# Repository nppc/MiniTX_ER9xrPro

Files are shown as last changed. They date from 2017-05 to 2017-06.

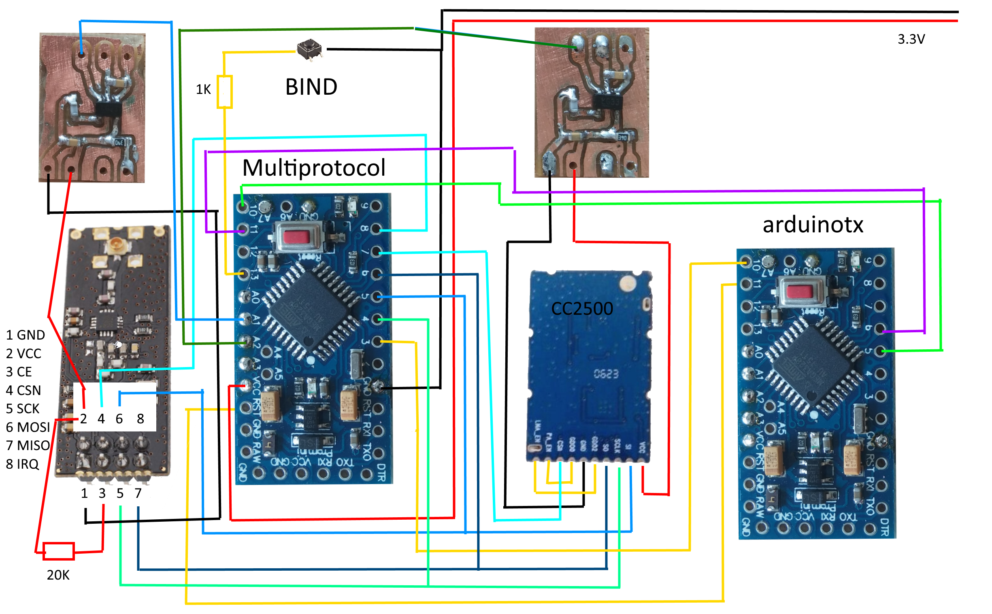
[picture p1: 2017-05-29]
Images/ProjectProtocol.png

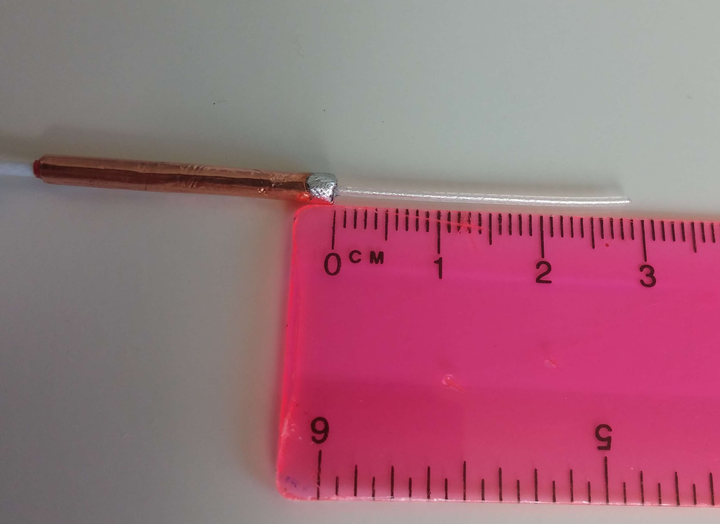
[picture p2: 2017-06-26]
Images/2_4ghzDipole1.jpg

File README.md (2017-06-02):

# MiniTX_ER9xrPro
Project for mini transmitter with gimbals from Er9xr Pro TX
# Transmitter software
Software is based on arduinorc project (http://www.reseau.org/arduinorc) with mine modifications.
Some of the modifications listed here:
- Added PRT variable to Models to store TX Protocol number
- Only configured models are selected with Model button
- Enter/exit Command mode done with push-button, not switch
- After model is selected, correct Protocol is choosed (rotary dip-switch emulation)
- Arming (Throttle Cut) is extended to 2 switches
- some other minor changes

## Change Models
To chnage models or to configure the transmitter, press and hold button "C" for 2 seconds to enter/exit Configuration mode.
So, to change Model you need to go to Configuration mode, press "M" button, and then exit from Configuration mode.
Every press of "M" button changes to the next Model. If next model is not configured, then first model is selected.

## Arm/disarm
Switches on side of the transmitter are used for safe arming. They are both connected to single analog channel A6 with resistors network.
If both swithces are OFF, then Throttle cut mode is activated.
If one of the swithces is ON, then Throttle cut mode is off.
For simple copters one of the switches can be used as arming switch.
For normal FC safe arming with 2 swithes is possible.

## Some Commands for configuring the transmitter
*To configure the transmitter, we need to go to Configure mode. In this mode enabled Serial interface at 2400 baud rate.*
- **DUMP** : print the values of all variables of current model
- **DUMP GLOBAL** : print the values of the Global variables
- **DUMP MODEL** : print the values of the Model variables of the current model
- **DUMP [channel]** : print the values of the Channel variables of the current model
- **DUMP MIXERS** : print the values of the Mixers variables of the current model
- **MODEL [number]** : select the model.
- **? (question mark)** : print the value of a variable (eg ? ICN1)
- **? POTx** : print the analog value of potentiometer x (POT1 = pin A0 ... POT8 = pin A7)
- **? PPM** : print the pulses widths of the PPM signal
- **? SWx** : print the logical value of switch x (SW1 = pin D2 ... SW3 = pin D4)
- **? VERSION** : print the version number of the software
- **? VOLT** : print the battery voltage
- **= (equal sign)** : change the value of a variable (eg ICN1=2)

## Variables for configuring transmitter
- **CDS** : current model ; this is the model number selected by the MODEL command.
- **TSC** : throttle cutoff value used by the throttle security check, [0-511] default = 50.
- **BAT** : minimum voltage required for Tx operation, an alarm is triggered when voltage gets lower. Value in the range [0-1023] default = 740.
- **KL1...KL8** : lowest analog value read on potentiometer #1, when the stick (and the hardware trim, if any) is at its lowest position. KL1...KL8 correspond to potentiometers 1 to 8. Value in the range [0-1023] default = 0.
- **KH1...KH8** : highest analog value read on potentiometer #1, when the stick (and the hardware trim, if any) is at its highest position. KH1...KH8 correspond to potentiometers 1 to 8. Value in the range [0-1023] default = 1023.

## Variables for configuring Models general data
- **NAM** : Model name, 8 characters, no spaces
- **THC** : Channel number used for throttle control, default=3, 0=no throttle channel.
- **PRT** : Protocol number of the Multiprotocol module that should be selected for current model. 1-FRSKYX_8CH, 2-FRSKYX_16CH, 3-FRSKYD, 4-FRSKYV, 5-BAYANG(H8), 6-BAYANG(H8S3D), 7-SYMAX (see Multiprotocol _Config.h for more protocols).

## Variables for configuring every channel of selected Model
*The name of a variable is composed of 3 letters and one figure. The figure is a channel number.
For instance, REV1 is the Reverse setting for channel 1, REV2 is the Reverse setting for channel 2.*
- **ICT** : Input control type: 1=potentiometer, 2=switch, 3=mixer, 0=off (do not read this control)
- **ICN** : Input control number: potentiometer number or switch number. Potentiometer number belongs to the interval [1,8]; Potentiometer 1 is connected to A0, pot 2 to A1, ... pot 8 to A7. Switch number belongs to the interval [1,6]; Switch 1 is connected to D2, switch 2 to D3, ... switch 6 to D7. Mixer number belongs to the interval [1,2]
- **REV** : Reverse, 1=servo direction is reversed for this channel, 0=servo direction is not reversed.
- **EXP** : Exponential applied symetrically from the center of this channel when the Dual Rate switch is ON. Percentage [0-100]. 0=none, 25=medium, 50=strong, 100=very strong. Exponential may also apply to the throttle channel (Model variable THC). This feature may be useful for gas engines. This exponential is calculated full-curve from 0.
- **PWL, PWH** : Minimal/Maximal pulse width for this channel, in microseconds. PWL default=720, PWH default=2200. These default values correspond to the Hextronic HXT500 servo and will accomodate most other servos. If your servos are moving erratically when you set the sticks near their minimum or maximum position, you must change these values: try with PWL=900 and PWH=2100. You can try to widen the default range to get a larger rotation angle if your servo supports it.
- **EPL, EPH** : End points position in percentage from the center of the channel [0,100]. EPL=low end point, EPH=high end point, both default=100. Set these variables if you want to limit the rotation angle of the servo.
- **SUB** : Subtrim signed percentage [-100,+100], default=0. Setting this variable shifts the neutral position of the servo in either direction, depending on the sign of the value: negative shifts left, positive shifts right.

# Multiprotocol Module software
Software is based on DIY Multiprotocol TX Module project (https://github.com/pascallanger/DIY-Multiprotocol-TX-Module) with mine modifications.

There is only two modifications:
- Adjusted prtocols list selected by rotary encoder (7 protocols can be selected)
- Antenna switch control pins (A1, A2) are used for turn on/off power to the RF module (CC2500 or NRF24L01)

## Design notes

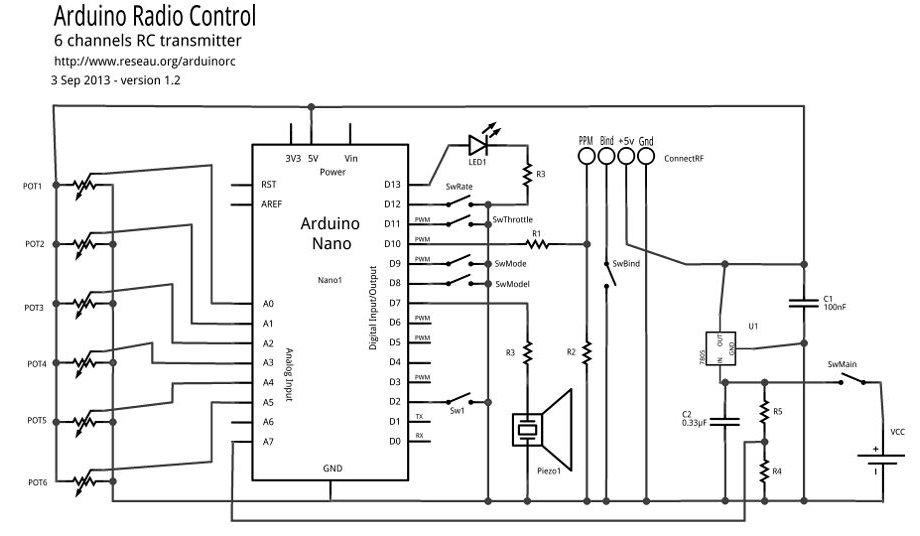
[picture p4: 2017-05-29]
Images/arduinorc.1.2a_schem_900.jpg

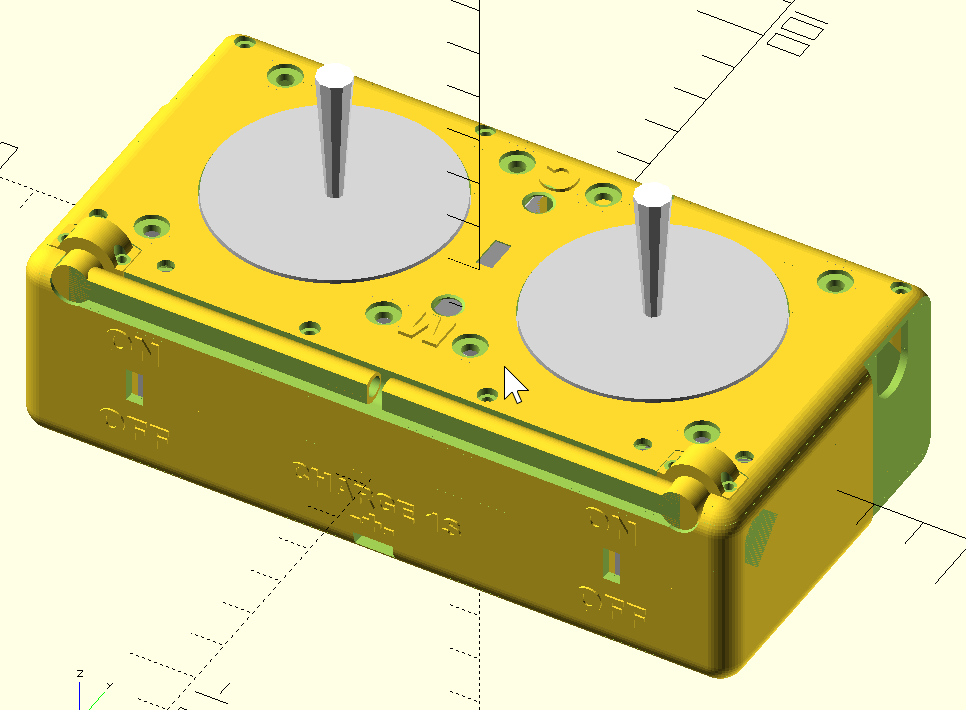
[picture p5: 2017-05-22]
Images/miniTX9xrProV2.scad.png

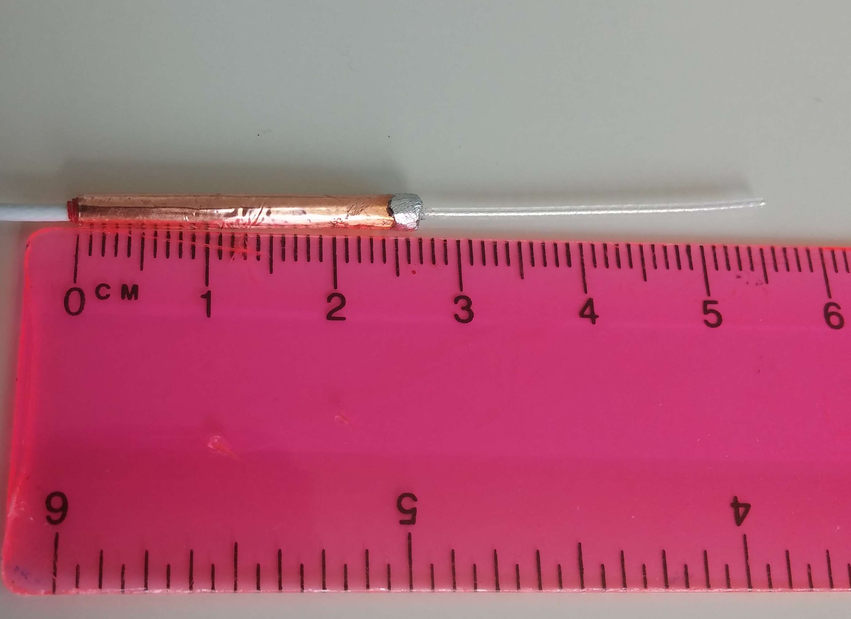
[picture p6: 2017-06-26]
Images/2_4ghzDipole2.jpg

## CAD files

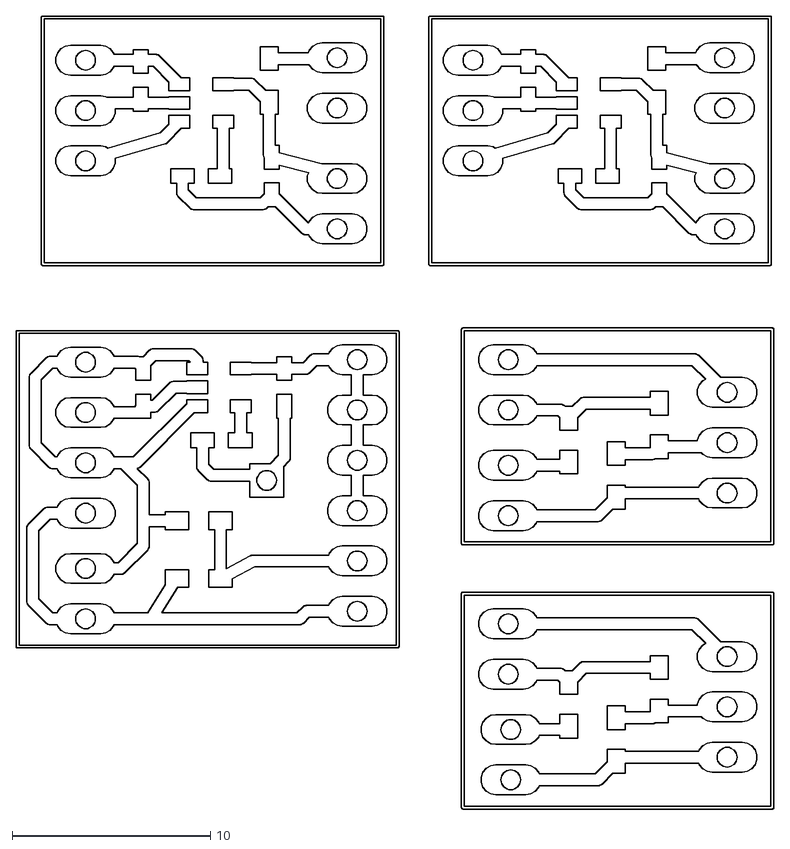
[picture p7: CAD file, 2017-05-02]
EstlCam/MiniTx_Er9XR_PRO-F.Cu.dxf
38.3 x 40.0

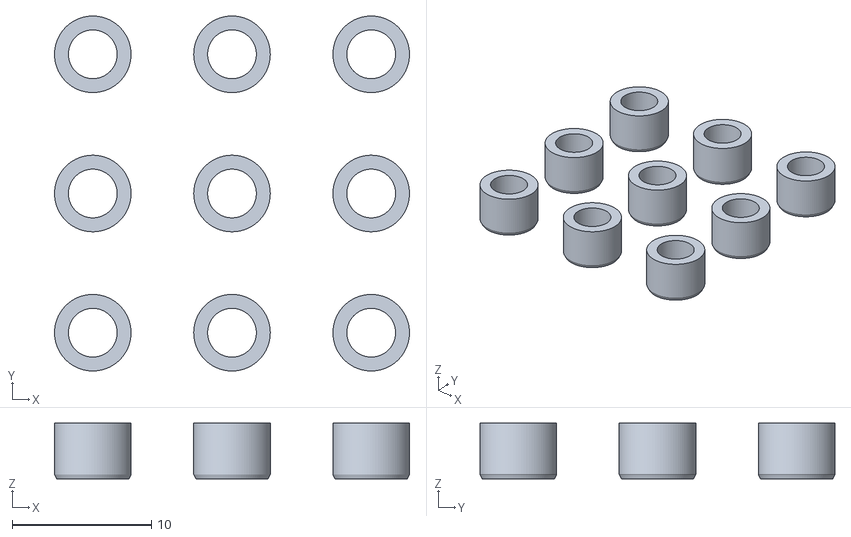
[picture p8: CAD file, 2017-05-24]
OpenSCAD/miniTX9xrProV2_spacers.stl
25.5 x 25.5 x 4.00

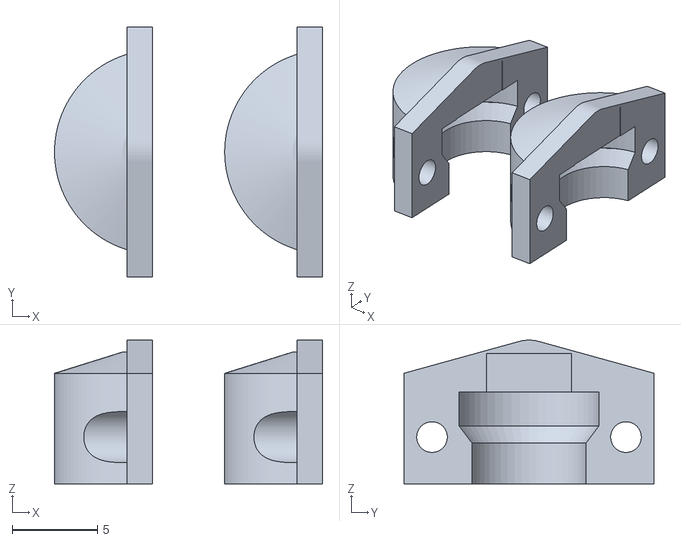
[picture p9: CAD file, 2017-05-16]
OpenSCAD/miniTX9xrProV2_antCoverX2.stl
15.8 x 14.7 x 8.45

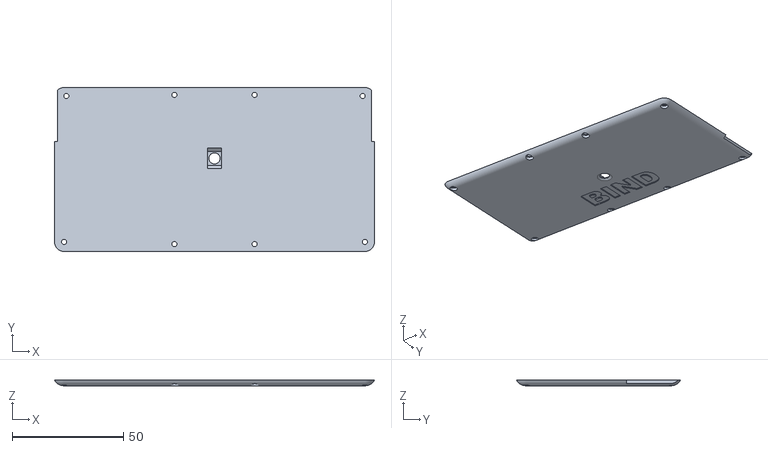
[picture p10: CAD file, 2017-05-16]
OpenSCAD/miniTX9xrProV2_bottom.stl
143.6 x 73.6 x 2.49

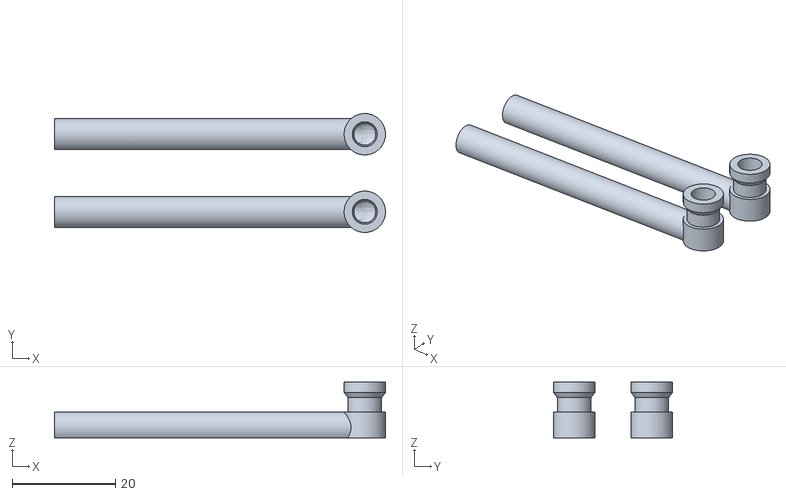
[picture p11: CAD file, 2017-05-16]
OpenSCAD/miniTX9xrProV2_antX2.stl
64.0 x 23.0 x 10.8

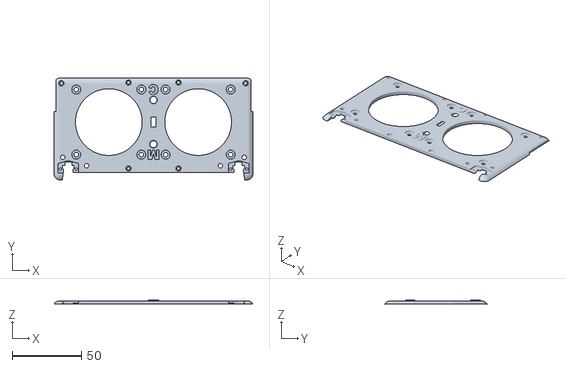
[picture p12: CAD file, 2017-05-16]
OpenSCAD/miniTX9xrProV2_top.stl
143.6 x 73.6 x 3.20

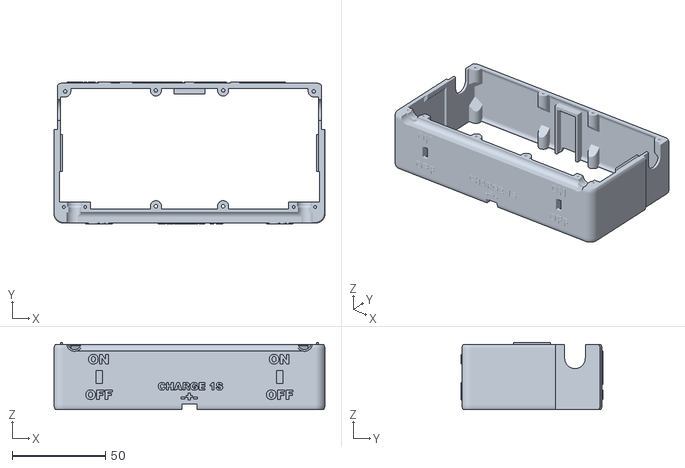
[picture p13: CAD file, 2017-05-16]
OpenSCAD/miniTX9xrProV2_middle.stl
145.0 x 75.8 x 36.0

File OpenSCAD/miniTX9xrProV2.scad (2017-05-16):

// mini transmitter with 9xr pro gimbals
// 1S battery for easy charging
$fn=100;

// CASE (upper wall 3mm, sides 2mm)
case_x=145;
case_y=75;
case_z=40;
case_roundness=10;

// GIMBAL
// distance between holes 47mm (quadrat)
 holedist=47; // distance between mounting holes
 roundcutout=47.5; // diameter of round part that comes out of the case 
 plate=54; // mounting plate size (where holes is)



caseTop();
caseMiddle();
caseBottom();
//rotate([0,-90,0]){antennacase();translate([0,15,0])antennacase();}
//rotate([0,-90,0]){antennamountcoverfull();translate([0,0,10])antennamountcoverfull();}


translate([case_x/2-11,-case_y/2+3,case_z/2-2])rotate([0,0,90]){
    //rotate([-90,0,0]){antennacase();dipole();}
    //antennamountcoverfull();
}
translate([-case_x/2+11,-case_y/2+3,case_z/2-2])rotate([0,0,90]){
    rotate([90,0,0]){antennacase();dipole();}
    antennamountcoverfull();
}



rotate([-180,0,0])rotate([0,90,180])translate([10,23,48.6])rotate([0,0,180])handsupport();

translate([-case_x/4+4,5,case_z/2-2.5])txgimbal();
/*
translate([case_x/4-4,5,case_z/2-2.5])rotate([0,0,180])txgimbal();




translate([0,-11,case_z/2-0.6])microdipswitch();
translate([0,11+10,case_z/2-0.6])microdipswitch();


translate([-case_x/3,-case_y/2+2,0])rotate([90,90,0])switch();
translate([case_x/3,-case_y/2+2,0])rotate([90,90,0])switch();



translate([-case_x/3.2,-case_y/2+13,case_z/2-25])rotate([90,0,0])cc2500();
translate([case_x/4.6,-case_y/2+13,case_z/2-12])rotate([90,0,0])NRF24L01P();
translate([-case_x/8,-case_y/2+10,case_z/2-20])rotate([90,90,0])arduinoMini();
translate([case_x/2-24,-case_y/2+10,case_z/2-29])rotate([90,0,0])arduinoNano();

translate([0,0,5])rotate([90,0,0])battery();
translate([0,0,5-13])rotate([90,0,0])battery();
*/

module caseTop() {
     difference(){
        union(){
            difference(){
                 case_upper(case_x,case_y,case_z,case_roundness);
                 translate([0,0,-1])case_upper(case_x-4,case_y-4,case_z-3,case_roundness-4);
            }
            // Model (M) text
            translate([4.6,-15,case_z/2-0.3])rotate([0,0,180])linear_extrude(height = 1){text("M", $fn = 20, size = 7, font = "ArialBlack");}
            // Config (C) text
            translate([3.8,32,case_z/2-0.3])rotate([0,0,180])linear_extrude(height = 1){text("C", $fn = 20, size = 7, font = "ArialBlack");}

        }
        // antenna cut
        translate([0,-case_y/2+3,case_z/2-3])rotate([0,90,0])antennacutout();
        translate([case_x/2-11,-case_y/2+3,case_z/2-2])rotate([0,0,90]){antennamounthole();antennamounthole_plate();}
        translate([-case_x/2+11,-case_y/2+3,case_z/2-2])rotate([0,0,90]){antennamounthole();antennamounthole_plate();}
        
       
        //cutout for leds
        translate([-case_x/2+7,-case_y/2+17,case_z/2-1])cutoutforled();
        translate([-case_x/3,-case_y/2+11,case_z/2-1])cutoutforled();
        translate([case_x/2-7,-case_y/2+17,case_z/2-1])cutoutforled();
        translate([case_x/3,-case_y/2+11,case_z/2-1])cutoutforled();
        
        //cutout for gimbals
        translate([case_x/4-4,5,case_z/2-2.5]){
            cylinder(d=roundcutout+0.6,h=6,center=true);
            holesforgimbalmount(3.3);
            translate([0,0,9])holesforgimbalmount(6.5);
        }
        translate([-case_x/4+4,5,case_z/2-2.5]){
            cylinder(d=roundcutout+0.6,h=6,center=true);
            holesforgimbalmount(3.3);
            translate([0,0,9])holesforgimbalmount(6.5);
        }
        
        // cutout for powerswitch
        translate([0,5,case_z/2-2.3])powerswitchholdercutout();
        
        //cutout for dipswitch
        translate([0,-11,case_z/2-0.6])hole_microdipswitch();
        translate([0,11+10,case_z/2-0.6])hole_microdipswitch();


        //cutout for hand holder
        translate([-case_x/2,case_y/2-10,0])cube([4,30,100],center=true);
        translate([case_x/2,case_y/2-10,0])cube([4,30,100],center=true);
        

    translate([0,0,-2.50])cube([case_x+1,case_y+1,case_z], center=true);
        
    translate([18,case_y/2-4,0])screwheadcut();
    translate([-18,case_y/2-4,0])screwheadcut();

    translate([case_x/2-6,case_y/2-4.5,0])screwheadcut();
    translate([-case_x/2+6,case_y/2-4.5,0])screwheadcut();
        
    translate([18,-case_y/2+9,0])screwheadcut();
    translate([-18,-case_y/2+9,0])screwheadcut();
        

    //reinforcements for join top/middle parts
    translate([-case_x/2+3,0,case_z/2-5.025])translate([1,0,3])cube([1.4,20.4,2], center=true);

    translate([case_x/2-3,0,case_z/2-5.025])rotate([0,0,180])        translate([1,0,3])cube([1.4,20.4,2], center=true);

    }

}

module caseMiddle(){
     difference(){
        union(){
            difference(){
                 case_upper(case_x,case_y,case_z,case_roundness);
                 translate([0,0,-1])case_upper(case_x-4,case_y-4,case_z-3,case_roundness-4);
                 cube([case_x-6,case_y-6,case_z], center=true);
            }
            difference(){
                case_lower(case_x,case_y,case_z,case_roundness);
                translate([0,0,1])case_lower(case_x-4,case_y-4,case_z-3,case_roundness-4);
                cube([case_x-6,case_y-6,case_z], center=true);
        }

            translate([0,-case_y/2+case_roundness/2-0.5,case_z/2-case_roundness/2])case_antennacutout();
            // meat for antenna holder (bottom)
            meatforAntennaholder_case();
            mirror([1,0,0])meatforAntennaholder_case();
            // reinforce for cutout handholder
            translate([-case_x/2+2.75,case_y/2-15.5,0])cube([1.5,26,36],center=true);
            translate([case_x/2-2.75,case_y/2-15.5,0])cube([1.5,26,36],center=true);
       
            texts();
        }
        // antenna cut
        translate([0,-case_y/2+3,case_z/2-3])rotate([0,90,0])antennacutout();
        translate([case_x/2-11,-case_y/2+3,case_z/2-2])rotate([0,0,90]){antennamounthole();}
        translate([-case_x/2+11,-case_y/2+3,case_z/2-2])rotate([0,0,90]){antennamounthole();}
        
        // cutouts for switches
        translate([-case_x/3,-case_y/2+2,0])cube([3.5,5,7], center=true);
        translate([case_x/3,-case_y/2+2,0])cube([3.5,5,7], center=true);
        

        //cutout for hand holder
        translate([-case_x/2,case_y/2-10,0])cube([4,30,100],center=true);
        translate([case_x/2,case_y/2-10,0])cube([4,30,100],center=true);

        // cutouts for switches
        translate([-case_x/3,-case_y/2+2,0])cube([3.5,5,7], center=true);
        translate([case_x/3,-case_y/2+2,0])cube([3.5,5,7], center=true);
        
        //cutout for charging 3 pin header
        translate([0,-case_y/2+2,-case_z/2+4])cube([8,6,3], center=true);

        //cutout for serial interface 5 pin header
        translate([0,case_y/2-2,-case_z/2+4])cube([13,6,3], center=true);
       


        translate([0,0,case_z-2.525])cube([case_x+1,case_y+1,case_z], center=true); // temp cut
        translate([0,0,-case_z+2.525])cube([case_x+1,case_y+1,case_z], center=true); // temp cut

    // hole for handsupport mounting
    rotate([-180,0,0])rotate([0,90,180])translate([10,23,0]){
        cylinder(d=11,h=case_x+2,center=true);
        translate([6,0,0])cube([11,11,case_x+2],center=true);
    }

    }
    
    //switch holders
    translate([-case_x/3,-case_y/2+2,0])rotate([90,90,0])switchholder();
    translate([case_x/3,-case_y/2+2,0])rotate([90,90,0])switchholder();
    // Battery holder
    translate([0,-case_y/2+4,0])batteryholder();
    translate([0,case_y/2-4,0])batteryholder();
    
    // case screws holders
    translate([18,case_y/2-4,9.975])case_mountinghole();
    translate([-18,case_y/2-4,9.975])case_mountinghole();
    
    
    translate([18,-case_y/2+9,9.975])case_mountingholefront();
    translate([-18,-case_y/2+9,9.975])case_mountingholefront();
    
    translate([case_x/2-6,case_y/2-4.5,9.975])case_mountinghole_corner();
    translate([-case_x/2+6,case_y/2-4.5,9.975])rotate([0,0,90])case_mountinghole_corner();
    

    // bottom screws sockets
    translate([18,case_y/2-4,-9.975])rotate([0,180,0])case_mountinghole();
    translate([-18,case_y/2-4,-9.975])rotate([0,180,0])case_mountinghole();

    translate([18,-case_y/2+4,-9.975])rotate([0,180,180])case_mountinghole();
    translate([-18,-case_y/2+4,-9.975])rotate([0,180,180])case_mountinghole();

    translate([-case_x/2+6,case_y/2-4.5,-9.975])rotate([0,180,0])case_mountinghole_corner();
    translate([case_x/2-6,case_y/2-4.5,-9.975])rotate([0,180,-90])case_mountinghole_corner();

    translate([case_x/2-5,-case_y/2+5,-9.975])rotate([0,180,180])case_mountinghole_corner();
    translate([-case_x/2+5,-case_y/2+5,-9.975])rotate([0,180,90])case_mountinghole_corner();

    //reinforcements for join top/middle parts
    translate([-case_x/2+3,0,case_z/2-5.025])reinforcement();
    translate([case_x/2-3,0,case_z/2-5.025])rotate([0,0,180])reinforcement();

}
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

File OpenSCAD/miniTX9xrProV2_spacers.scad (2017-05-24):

$fn=90;
for(ix=[0:10:20])for(iy=[0:10:20])translate([ix,iy,0])spacer();
    
module spacer(){
    difference(){
        union(){
            cylinder(d=5.5, h=3.7, center=true);
            translate([0,0,-2])cylinder(d2=5.5, d1=5.2, h=0.3, center=true);
        }
        cylinder(d=3.5,h=5,center=true);
        translate([0,0,-2.05])cylinder(d1=3.8,d2=3.5, h=0.3,center=true);
    }
}

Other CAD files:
OpenSCAD/miniTX9xrPro.scad

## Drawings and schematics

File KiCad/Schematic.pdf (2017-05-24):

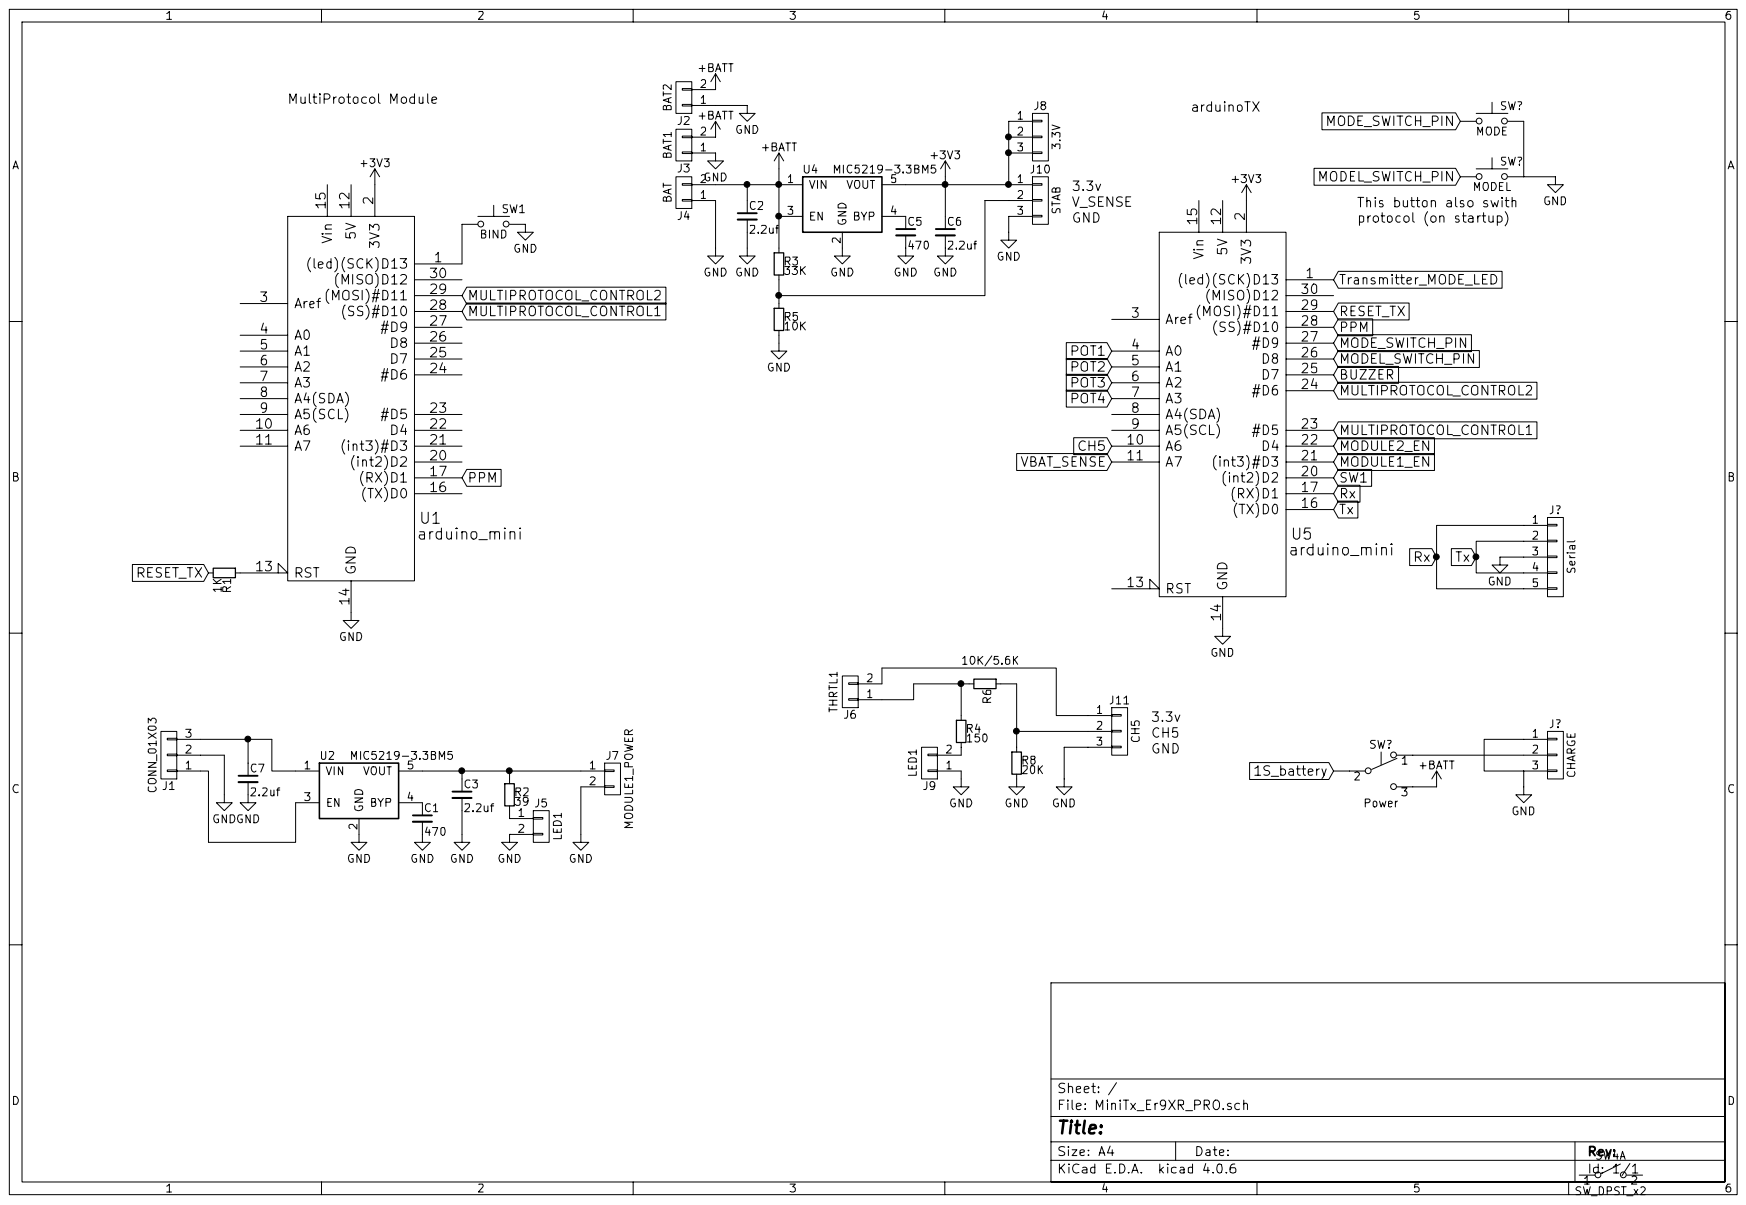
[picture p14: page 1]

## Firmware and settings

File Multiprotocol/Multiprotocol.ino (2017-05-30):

/*********************************************************
					Multiprotocol Tx code
               by Midelic and Pascal Langer(hpnuts)
	http://www.rcgroups.com/forums/showthread.php?t=2165676
    https://github.com/pascallanger/DIY-Multiprotocol-TX-Module/edit/master/README.md

	Thanks to PhracturedBlue, Hexfet, Goebish, Victzh and all protocol developers
				Ported  from deviation firmware 

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
 You should have received a copy of the GNU General Public License
 along with Multiprotocol.  If not, see <http://www.gnu.org/licenses/>.
*/
#include <avr/pgmspace.h>
//#define DEBUG_TX
//#define USE_MY_CONFIG
#include "Multiprotocol.h"

//Multiprotocol module configuration file
#include "_Config.h"
// Let's automatically select the board
// if arm is selected
#ifdef __arm__
	#define STM32_BOARD
#endif

//Personal config file
#if defined USE_MY_CONFIG
	#include "_MyConfig.h"
#endif

#include "Pins.h"
#include "TX_Def.h"
#include "Validate.h"

#ifndef STM32_BOARD
	#include <avr/eeprom.h>
#else
	#include <arduino.h>
	#include <libmaple/usart.h>
	#include <libmaple/timer.h>
	#include <SPI.h>	
	#include <EEPROM.h>	
	HardwareTimer timer(2);
	void PPM_decode();
	void ISR_COMPB();
	extern "C"
	{
		void __irq_usart2(void);
		void __irq_usart3(void);
	}
#endif

//Global constants/variables
uint32_t MProtocol_id;//tx id,
uint32_t MProtocol_id_master;
uint32_t blink=0,last_signal=0;
//
uint16_t counter;
uint8_t  channel;
uint8_t  packet[40];

#define NUM_CHN 16
// Servo data
uint16_t Servo_data[NUM_CHN];
uint8_t  Servo_AUX;
uint16_t servo_max_100,servo_min_100,servo_max_125,servo_min_125;
uint16_t servo_mid;

// Protocol variables
uint8_t  cyrfmfg_id[6];//for dsm2 and devo
uint8_t  rx_tx_addr[5];
uint8_t  rx_id[4];
uint8_t  phase;
uint16_t bind_counter;
uint8_t  bind_phase;
uint8_t  binding_idx;
uint16_t packet_period;
uint8_t  packet_count;
uint8_t  packet_sent;
uint8_t  packet_length;
uint8_t  hopping_frequency[50];
uint8_t  *hopping_frequency_ptr;
uint8_t  hopping_frequency_no=0;
uint8_t  rf_ch_num;
uint8_t  throttle, rudder, elevator, aileron;
uint8_t  flags;
uint16_t crc;
uint8_t  crc8;
uint16_t seed;
//
uint16_t state;
uint8_t  len;
uint8_t  RX_num;

#if defined(FRSKYX_CC2500_INO) || defined(SFHSS_CC2500_INO)
	uint8_t calData[48];
#endif

//Channel mapping for protocols
const uint8_t CH_AETR[]={AILERON, ELEVATOR, THROTTLE, RUDDER, AUX1, AUX2, AUX3, AUX4, AUX5, AUX6, AUX7, AUX8, AUX9, AUX10};
const uint8_t CH_TAER[]={THROTTLE, AILERON, ELEVATOR, RUDDER, AUX1, AUX2, AUX3, AUX4, AUX5, AUX6, AUX7, AUX8};
const uint8_t CH_RETA[]={RUDDER, ELEVATOR, THROTTLE, AILERON, AUX1, AUX2, AUX3, AUX4, AUX5, AUX6, AUX7, AUX8};
const uint8_t CH_EATR[]={ELEVATOR, AILERON, THROTTLE, RUDDER, AUX1, AUX2, AUX3, AUX4, AUX5, AUX6, AUX7, AUX8};

// Mode_select variables
uint8_t mode_select;
uint8_t protocol_flags=0,protocol_flags2=0;

// PPM variable
volatile uint16_t PPM_data[NUM_CHN];

#ifndef ORANGE_TX
//Random variable
volatile uint32_t gWDT_entropy=0;
#endif

//Serial protocol
uint8_t sub_protocol;
uint8_t protocol;
uint8_t option;
uint8_t cur_protocol[3];
uint8_t prev_option;
uint8_t prev_power=0xFD; // unused power value

//Serial RX variables
#define BAUD 100000
#define RXBUFFER_SIZE 26
volatile uint8_t rx_buff[RXBUFFER_SIZE];
volatile uint8_t rx_ok_buff[RXBUFFER_SIZE];
volatile uint8_t discard_frame = 0;

// Telemetry
#define MAX_PKT 29
uint8_t pkt[MAX_PKT];//telemetry receiving packets
#if defined(TELEMETRY)
	#ifdef INVERT_TELEMETRY
		#if not defined(ORANGE_TX) && not defined(STM32_BOARD)
			// enable bit bash for serial
			#define	BASH_SERIAL 1
		#endif
		#define	INVERT_SERIAL 1
	#endif
	uint8_t pass = 0;
	uint8_t pktt[MAX_PKT];//telemetry receiving packets
	#ifdef BASH_SERIAL
	// For bit-bashed serial output
		#define TXBUFFER_SIZE 128
		volatile struct t_serial_bash
		{
			uint8_t head ;
			uint8_t tail ;
			uint8_t data[TXBUFFER_SIZE] ;
			uint8_t busy ;
			uint8_t speed ;
		} SerialControl ;
	#else
		#define TXBUFFER_SIZE 64
		volatile uint8_t tx_buff[TXBUFFER_SIZE];
		volatile uint8_t tx_head=0;
		volatile uint8_t tx_tail=0;
	#endif // BASH_SERIAL
	uint8_t v_lipo1;
	uint8_t v_lipo2;
	uint8_t RX_RSSI;
	uint8_t TX_RSSI;
	uint8_t RX_LQI;
	uint8_t TX_LQI;
	uint8_t telemetry_link=0; 
	uint8_t telemetry_counter=0;
	uint8_t telemetry_lost;
#endif 

// Callback
typedef uint16_t (*void_function_t) (void);//pointer to a function with no parameters which return an uint16_t integer
void_function_t remote_callback = 0;

// Init
void setup()
{
	// General pinout
	#ifdef ORANGE_TX
		//XMEGA
		PORTD.OUTSET = 0x17 ;
		PORTD.DIRSET = 0xB2 ;
		PORTD.DIRCLR = 0x4D ;
		PORTD.PIN0CTRL = 0x18 ;
		PORTD.PIN2CTRL = 0x18 ;
		PORTE.DIRSET = 0x01 ;
		PORTE.DIRCLR = 0x02 ;
		// Timer1 config
		// TCC1 16-bit timer, clocked at 0.5uS
		EVSYS.CH3MUX = 0x80 + 0x04 ;	// Prescaler of 16
		TCC1.CTRLB = 0; TCC1.CTRLC = 0; TCC1.CTRLD = 0; TCC1.CTRLE = 0;
		TCC1.INTCTRLA = 0; TIMSK1 = 0;
		TCC1.PER = 0xFFFF ;
		TCNT1 = 0 ;
		TCC1.CTRLA = 0x0B ;	// Event3 (prescale of 16)
	#elif defined STM32_BOARD
		//STM32
		afio_cfg_debug_ports(AFIO_DEBUG_NONE);
		pinMode(A7105_CSN_pin,OUTPUT);
		pinMode(CC25_CSN_pin,OUTPUT);
		pinMode(NRF_CSN_pin,OUTPUT);
		pinMode(CYRF_CSN_pin,OUTPUT);
		pinMode(CYRF_RST_pin,OUTPUT);
		pinMode(PE1_pin,OUTPUT);
		pinMode(PE2_pin,OUTPUT);
		#if defined TELEMETRY
			pinMode(TX_INV_pin,OUTPUT);
			pinMode(RX_INV_pin,OUTPUT);
			#if defined INVERT_SERIAL
				TX_INV_on;//activated inverter for both serial TX and RX signals
				RX_INV_on;
			#else
				TX_INV_off;
				RX_INV_off;
			#endif	
		#endif
		pinMode(BIND_pin,INPUT_PULLUP);
		pinMode(PPM_pin,INPUT);
		pinMode(S1_pin,INPUT_PULLUP);//dial switch
		pinMode(S2_pin,INPUT_PULLUP);
		pinMode(S3_pin,INPUT_PULLUP);
		pinMode(S4_pin,INPUT_PULLUP);
		//Random pins
		pinMode(PB0, INPUT_ANALOG); // set up pin for analog input
		pinMode(PB1, INPUT_ANALOG); // set up pin for analog input

		//select the counter clock.
		start_timer2();//0.5us
	#else
		//ATMEGA328p
		// all inputs
		DDRB=0x00;DDRC=0x00;DDRD=0x00;
		// outputs
		SDI_output;
		SCLK_output;
		#ifdef A7105_CSN_pin
			A7105_CSN_output;
		#endif
		#ifdef CC25_CSN_pin
			CC25_CSN_output;
		#endif
		#ifdef CYRF_CSN_pin
			CYRF_RST_output;
			CYRF_CSN_output;
		#endif
		#ifdef NRF_CSN_pin
			NRF_CSN_output;
		#endif
		PE1_output;
		PE2_output;
		// at the beginning all modules are on
		PE1_on; 
		PE2_on;
		SERIAL_TX_output;

		// pullups
		MODE_DIAL1_port |= _BV(MODE_DIAL1_pin);
		MODE_DIAL2_port |= _BV(MODE_DIAL2_pin);
		MODE_DIAL3_port |= _BV(MODE_DIAL3_pin);
		MODE_DIAL4_port |= _BV(MODE_DIAL4_pin);
		BIND_port |= _BV(BIND_pin);

		// Timer1 config
		TCCR1A = 0;
		TCCR1B = (1 << CS11);	//prescaler8, set timer1 to increment every 0.5us(16Mhz) and start timer
		
		// Random
		random_init();
	#endif

	// Set Chip selects
	#ifdef A7105_CSN_pin
		A7105_CSN_on;
	#endif
	#ifdef CC25_CSN_pin
		CC25_CSN_on;
	#endif
	#ifdef CYRF_CSN_pin
		CYRF_CSN_on;
	#endif
	#ifdef NRF_CSN_pin
		NRF_CSN_on;
	#endif
	//	Set SPI lines
	#ifdef	STM32_BOARD
		initSPI2();
	#else
		SDI_on;
		SCLK_off;
	#endif

	// Set servos positions
	for(uint8_t i=0;i<NUM_CHN;i++)
		Servo_data[i]=1500;
	Servo_data[THROTTLE]=servo_min_100;
	#ifdef ENABLE_PPM
		memcpy((void *)PPM_data,Servo_data, sizeof(Servo_data));
	#endif
	
	//Wait for every component to start
	delayMilliseconds(100);
	
	// Read status of bind button
	if( IS_BIND_BUTTON_on )
		BIND_BUTTON_FLAG_on;	// If bind button pressed save the status for protocol id reset under hubsan

	// Read status of mode select binary switch
	// after this mode_select will be one of {0000, 0001, ..., 1111}
	#ifndef ENABLE_PPM
		mode_select = MODE_SERIAL ;	// force serial mode
	#elif defined STM32_BOARD
		mode_select= 0x0F -(uint8_t)(((GPIOA->regs->IDR)>>4)&0x0F);
	#else
		mode_select =
			((MODE_DIAL1_ipr & _BV(MODE_DIAL1_pin)) ? 0 : 1) + 
			((MODE_DIAL2_ipr & _BV(MODE_DIAL2_pin)) ? 0 : 2) +
			((MODE_DIAL3_ipr & _BV(MODE_DIAL3_pin)) ? 0 : 4) +
			((MODE_DIAL4_ipr & _BV(MODE_DIAL4_pin)) ? 0 : 8);
	#endif

	// Update LED
	LED_off;
	LED_output; 

	//Init RF modules
	modules_reset();

#ifndef ORANGE_TX
	//Init the seed with a random value created from watchdog timer for all protocols requiring random values
	#ifdef STM32_BOARD
		randomSeed((uint32_t)analogRead(PB0) << 10 | analogRead(PB1));			
	#else
		randomSeed(random_value());
	#endif
#endif

	// Read or create protocol id
	MProtocol_id_master=random_id(10,false);
	
#ifdef ENABLE_PPM
	//Protocol and interrupts initialization
	if(mode_select != MODE_SERIAL)
	{ // PPM
		mode_select--;
		protocol		=	PPM_prot[mode_select].protocol;
		cur_protocol[1] = protocol;
		sub_protocol   	=	PPM_prot[mode_select].sub_proto;
		RX_num			=	PPM_prot[mode_select].rx_num;
		option			=	PPM_prot[mode_select].option;
		if(PPM_prot[mode_select].power)		POWER_FLAG_on;
		if(PPM_prot[mode_select].autobind)	AUTOBIND_FLAG_on;
		mode_select++;
		servo_max_100=PPM_MAX_100; servo_min_100=PPM_MIN_100;
		servo_max_125=PPM_MAX_125; servo_min_125=PPM_MIN_125;

		protocol_init();

		#ifndef STM32_BOARD
			//Configure PPM interrupt
			#if PPM_pin == 2
				EICRA |= _BV(ISC01);	// The rising edge of INT0 pin D2 generates an interrupt request
				EIMSK |= _BV(INT0);		// INT0 interrupt enable
			#elif PPM_pin == 3
				EICRA |= _BV(ISC11);	// The rising edge of INT1 pin D3 generates an interrupt request
				EIMSK |= _BV(INT1);		// INT1 interrupt enable
			#else
				#error PPM pin can only be 2 or 3
			#endif
		#else
			attachInterrupt(PPM_pin,PPM_decode,FALLING);
		#endif

		#if defined(TELEMETRY)
			PPM_Telemetry_serial_init();// Configure serial for telemetry
		#endif
	}
	else
#endif //ENABLE_PPM
	{ // Serial
		#ifdef ENABLE_SERIAL
			for(uint8_t i=0;i<3;i++)
				cur_protocol[i]=0;
			protocol=0;
			servo_max_100=SERIAL_MAX_100; servo_min_100=SERIAL_MIN_100;
			servo_max_125=SERIAL_MAX_125; servo_min_125=SERIAL_MIN_125;
			Mprotocol_serial_init(); 	// Configure serial and enable RX interrupt
		#endif //ENABLE_SERIAL
	}
	servo_mid=servo_min_100+servo_max_100;	//In fact 2* mid_value
}

// Main
// Protocol scheduler
void loop()
{ 
	uint16_t next_callback,diff=0xFFFF;

	while(1)
	{
		if(remote_callback==0 || IS_WAIT_BIND_on || diff>2*200)
		{
			do
			{
				Update_All();
			}
			while(remote_callback==0 || IS_WAIT_BIND_on);
		}
		#ifndef STM32_BOARD
			if( (TIFR1 & OCF1A_bm) != 0)
			{
				cli();					// Disable global int due to RW of 16 bits registers
				OCR1A=TCNT1;			// Callback should already have been called... Use "now" as new sync point.
				sei();					// Enable global int
			}
			else
				while((TIFR1 & OCF1A_bm) == 0); // Wait before callback
		#else
			if((TIMER2_BASE->SR & TIMER_SR_CC1IF)!=0)
			{
				cli();
				OCR1A = TCNT1;
				sei();
			}
			else
				while((TIMER2_BASE->SR & TIMER_SR_CC1IF )==0); // Wait before callback
		#endif
		do
		{
			TX_MAIN_PAUSE_on;
			tx_pause();
			if(IS_INPUT_SIGNAL_on && remote_callback!=0)
				next_callback=remote_callback();
			else
				next_callback=2000;					// No PPM/serial signal check again in 2ms...
			TX_MAIN_PAUSE_off;
			tx_resume();
			while(next_callback>4000)
			{ // start to wait here as much as we can...
				next_callback-=2000;				// We will wait below for 2ms
				cli();								// Disable global int due to RW of 16 bits registers
				OCR1A += 2000*2 ;					// set compare A for callback
				#ifndef STM32_BOARD	
					TIFR1=OCF1A_bm;					// clear compare A=callback flag
				#else
					TIMER2_BASE->SR &= ~TIMER_SR_CC1IF;	//clear compare Flag
				#endif
				sei();								// enable global int
				if(Update_All())					// Protocol changed?
				{
					next_callback=0;				// Launch new protocol ASAP
					break;
				}
				#ifndef STM32_BOARD	
					while((TIFR1 & OCF1A_bm) == 0);	// wait 2ms...
				#else
					while((TIMER2_BASE->SR & TIMER_SR_CC1IF)==0);//2ms wait
				#endif
			}
			// at this point we have a maximum of 4ms in next_callback
			next_callback *= 2 ;
			cli();									// Disable global int due to RW of 16 bits registers
			OCR1A+= next_callback ;					// set compare A for callback
			#ifndef STM32_BOARD			
				TIFR1=OCF1A_bm;						// clear compare A=callback flag
			#else
				TIMER2_BASE->SR &= ~TIMER_SR_CC1IF;	//clear compare Flag write zero 
			#endif		
			diff=OCR1A-TCNT1;						// compare timer and comparator
			sei();									// enable global int
		}
		while(diff&0x8000);	 						// Callback did not took more than requested time for next callback
													// so we can launch Update_All before next callback
	}
}

uint8_t Update_All()
{
	#ifdef ENABLE_SERIAL
		if(mode_select==MODE_SERIAL && IS_RX_FLAG_on)		// Serial mode and something has been received
		{
			update_serial_data();							// Update protocol and data
			update_channels_aux();
			INPUT_SIGNAL_on;								//valid signal received
			last_signal=millis();
		}
	#endif //ENABLE_SERIAL
	#ifdef ENABLE_PPM
		if(mode_select!=MODE_SERIAL && IS_PPM_FLAG_on)		// PPM mode and a full frame has been received
		{
			for(uint8_t i=0;i<MAX_PPM_CHANNELS;i++)
			{ // update servo data without interrupts to prevent bad read in protocols
				uint16_t temp_ppm ;
				cli();										// disable global int
				temp_ppm = PPM_data[i] ;
				sei();										// enable global int
				if(temp_ppm<PPM_MIN_125) temp_ppm=PPM_MIN_125;
				else if(temp_ppm>PPM_MAX_125) temp_ppm=PPM_MAX_125;
				Servo_data[i]= temp_ppm ;
			}
			PPM_FLAG_off;									// wait for next frame before update
			update_channels_aux();
			INPUT_SIGNAL_on;								//valid signal received
			last_signal=millis();
		}
	#endif //ENABLE_PPM
	update_led_status();
	#if defined(TELEMETRY)
		#if ( !( defined(MULTI_TELEMETRY) || defined(MULTI_STATUS) ) )
			if((protocol==MODE_FRSKYD) || (protocol==MODE_BAYANG) || (protocol==MODE_HUBSAN) || (protocol==MODE_AFHDS2A) || (protocol==MODE_FRSKYX) || (protocol==MODE_DSM) )
		#endif
				TelemetryUpdate();
	#endif
	#ifdef ENABLE_BIND_CH
		if(IS_AUTOBIND_FLAG_on && IS_BIND_CH_PREV_off && Servo_data[BIND_CH-1]>PPM_MAX_COMMAND && Servo_data[THROTTLE]<(servo_min_100+25))
		{ // Autobind is on and BIND_CH went up and Throttle is low
			CHANGE_PROTOCOL_FLAG_on;							//reload protocol to rebind
			BIND_CH_PREV_on;
		}
		if(IS_BIND_CH_PREV_on && Servo_data[BIND_CH-1]<PPM_MIN_COMMAND)
		{
			BIND_CH_PREV_off;
			#if defined(FRSKYD_CC2500_INO) || defined(FRSKYX_CC2500_INO) || defined(FRSKYV_CC2500_INO)
			if(protocol==MODE_FRSKYD || protocol==MODE_FRSKYX || protocol==MODE_FRSKYV)
				BIND_DONE;
			else
			#endif
			if(bind_counter>2)
				bind_counter=2;
		}
	#endif //ENABLE_BIND_CH
	if(IS_CHANGE_PROTOCOL_FLAG_on)
	{ // Protocol needs to be changed or relaunched for bind
		protocol_init();									//init new protocol
		return 1;
	}
	return 0;
}

// Update channels direction and Servo_AUX flags based on servo AUX positions
static void update_channels_aux(void)
{
	//Reverse channels direction
	#ifdef REVERSE_AILERON
		Servo_data[AILERON]=servo_mid-Servo_data[AILERON];
	#endif
	#ifdef REVERSE_ELEVATOR
		Servo_data[ELEVATOR]=servo_mid-Servo_data[ELEVATOR];
	#endif
	#ifdef REVERSE_THROTTLE
		Servo_data[THROTTLE]=servo_mid-Servo_data[THROTTLE];
	#endif
	#ifdef REVERSE_RUDDER
		Servo_data[RUDDER]=servo_mid-Servo_data[RUDDER];
	#endif
	//Calc AUX flags
	Servo_AUX=0;
	for(uint8_t i=0;i<8;i++)
		if(Servo_data[AUX1+i]>PPM_SWITCH)
			Servo_AUX|=1<<i;
}

// Update led status based on binding and serial
static void update_led_status(void)
{
	if(IS_INPUT_SIGNAL_on)
		if(millis()-last_signal>70)
			INPUT_SIGNAL_off;							//no valid signal (PPM or Serial) received for 70ms
	if(blink<millis())
	{
		if(IS_INPUT_SIGNAL_off)
		{
			if(mode_select==MODE_SERIAL)
				blink+=BLINK_SERIAL_TIME;				//blink slowly if no valid serial input
			else
				blink+=BLINK_PPM_TIME;					//blink more slowly if no valid PPM input
		}
		else
			if(remote_callback == 0)
			{ // Invalid protocol
				if(IS_LED_on)							//flash to indicate invalid protocol
					blink+=BLINK_BAD_PROTO_TIME_LOW;
				else
					blink+=BLINK_BAD_PROTO_TIME_HIGH;
			}
			else
			{
				if(IS_WAIT_BIND_on)
				{
					if(IS_LED_on)							//flash to indicate WAIT_BIND
						blink+=BLINK_WAIT_BIND_TIME_LOW;
					else
						blink+=BLINK_WAIT_BIND_TIME_HIGH;
				}
				else
				{
					if(IS_BIND_DONE_on)
						LED_off;							//bind completed force led on
					blink+=BLINK_BIND_TIME;					//blink fastly during binding
				}
			}
		LED_toggle;
	}
}

inline void tx_pause()
{
	#ifdef TELEMETRY
	// Pause telemetry by disabling transmitter interrupt
		#ifdef ORANGE_TX
			USARTC0.CTRLA &= ~0x03 ;
		#else
			#ifndef BASH_SERIAL
				#ifdef STM32_BOARD
					USART3_BASE->CR1 &= ~ USART_CR1_TXEIE;
				#else
					UCSR0B &= ~_BV(UDRIE0);
				#endif
			#endif
		#endif
	#endif
}

inline void tx_resume()
{
	#ifdef TELEMETRY
	// Resume telemetry by enabling transmitter interrupt
		if(!IS_TX_PAUSE_on)
		{
			#ifdef ORANGE_TX
				cli() ;
				USARTC0.CTRLA = (USARTC0.CTRLA & 0xFC) | 0x01 ;
				sei() ;
			#else
				#ifndef BASH_SERIAL
					#ifdef STM32_BOARD
						USART3_BASE->CR1 |= USART_CR1_TXEIE;
					#else
						UCSR0B |= _BV(UDRIE0);			
					#endif
				#else
					resumeBashSerial();
				#endif
			#endif
		}
	#endif
}

#ifdef STM32_BOARD	
void start_timer2()
{	
	// Pause the timer while we're configuring it
	timer.pause();
	TIMER2_BASE->PSC = 35;			//36-1;for 72 MHZ /0.5sec/(35+1)
	TIMER2_BASE->ARR = 0xFFFF;		//count till max
	timer.setMode(TIMER_CH1, TIMER_OUTPUT_COMPARE);
	timer.setMode(TIMER_CH2, TIMER_OUTPUT_COMPARE);
	// Refresh the timer's count, prescale, and overflow
	timer.refresh();
	timer.resume();
}
#endif
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

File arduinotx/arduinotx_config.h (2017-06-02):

/* arduinotx_config.h - Tx configuration ; all user-customizable settings are defined here
** Edit this file as needed. Normally, you do not have to make changes to any other file.
** 28-05-2014
*/

/* Copyright (C) 2014 Richard Goutorbe.  All right reserved.
This program is free software: you can redistribute it and/or modify it under the terms of the GNU General Public License as published by the Free Software Foundation, version 3.
This program is distributed in the hope that it will be useful, but WITHOUT ANY WARRANTY; without even the implied warranty of  MERCHANTABILITY or FITNESS FOR A PARTICULAR PURPOSE.
See the GNU General Public License for more details. You should have received a copy of the GNU General Public License along with this program.  If not, see <http://www.gnu.org/licenses/>.
Contact information: http://www.reseau.org/arduinorc/index.php?n=Main.Contact
*/

#ifndef arduinotx_config_h
#define arduinotx_config_h

// ----------------------------------------------------------------------------------------
// Hardware settings
// ----------------------------------------------------------------------------------------

// Number of channels [1,9]
// With the Arduino Nano, 8 analog input pins: A0 to A7 are available for
// proportional channels, and 6 digital input pins: D2 to D7 for discrete channels
// You can configure each channel to use either a potentiometer or a switch,
// see model variables ICT and ICN
#define CHANNELS 6

#include "arduinotx_eeprom.h" // this include must follow CHANNELS definition

// Number of potentiometers (8 max) installed in the transmitter
// With the Arduino Nano, 8 analog input pins: A0 to A7 are available for proportional channels
// Potentiometer 1 is connected to A0, pot 2 to A1, ... pot 8 to A7
#define NPOTS 7	// ch5 mapped to A6 is for Flight Controller mode changes (CH5 has own circuity)

// Number of user switches (6 max) installed in the transmitter for discrete channels
// With the Arduino Nano, 6 digital input pins: D2 to D7 are available 
// Switch 1 is connected to D2, switch 2 to D3, ... switch 6 to D7
#define NSWITCHES  1 //(NPPC for future needs (change acro/stab mode for Eachine H8 for example)

// The led is connected to this pin
#define LED_PIN  13

// Buzzer (optional); comment this line if you do not implement it
#define BUZZER_ENABLED
// The buzzer is connected to this pin
#define BUZZER_PIN 7

// Battery check (optional); comment this line if you do not implement it
#define BATCHECK_ENABLED
// Analog pin connected to the 1/2 voltage divider
#define BATCHECK_PIN  A7
// We are using VCC voltage reference 3.3V
// Battery voltage correction: if PRINT VOLT does not return the exact voltage measured with a multimeter,
// then you define the correction here. In my case, PRINT VOLT returns 4.2V and my multimeter 4.1V
// so the correction should be - 0.1V ; and since 1V is 155 (in ADC units, see ArduinoTx::ReadBattery()) then 0.1V is int(15.5) = - 15 ADC units
// like this: #define BATVOLT_CORRECTION -15
#define BATVOLT_CORRECTION 0

// Switches used to configure the transmitter, not to control channels
// A switch is ON when opened because there is a pullup resistor on the corresponding input
#define MODE_SWITCH_PIN 9			// opened=transmission, closed=command mode
#define THROTTLECUT_SWITCH_PIN A6	// NPPC (Same as POT5 (ch5). While reading this pin we will invert value. Pulldown resistor is connected here)
//#define DUALRATE_SWITCH_PIN 12	// opened=dual rate ON, closed=OFF (NPPC we will not using Dual Rates switch)
#define MODEL_SWITCH_PIN 8		// opened=use model selected by the MODEL command (CDS global variable), closed=use model corresponding to the ADS global variable
								// Also will be read during startup to choose from one of three TX protocols.

// define two pins for choosing protocol of MultiProtocol module (currently only three protocols)
#define MULTIPROTOCOL_CONTROL1_PIN 5		// connected as rotary encoder of MultiProtocol module
#define MULTIPROTOCOL_CONTROL2_PIN 6		// connected as rotary encoder of MultiProtocol module
#define MULTIPROTOCOL_CONTROL3_PIN 12		// connected as rotary encoder of MultiProtocol module
#define MULTIPROTOCOL_RESET_PIN 11		    // On/Off TX arduino


// next 2 const are used only if MODEL_SWITCH_BEHAVIOUR == MODEL_SWITCH_ROTATING (see below)
//#define MODEL_ROTATING_SWITCH_PIN A6 		// use an analog input to read the rotating switch position (NPPC we will reuse this pin)
#define MODEL_ROTATING_SWITCH_STEPS 10 	// my rotating switch has 10 steps; you must customize this value

// ----------------------------------------------------------------------------------------
// Software settings
// ----------------------------------------------------------------------------------------
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

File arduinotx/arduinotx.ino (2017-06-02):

/* arduinotx.ino - Open source RC transmitter software for the Arduino 
** 27-07-2012
** 08-08-2012 send_ppm() fixed
** 20-09-2012 calibration
** 15-10-2012 ReadControl(), ICT_OFF, ICT_SLAVE
** 25-10-2012 generate PPM signal with Timer1 ISR
** 28-10-2012 get_test_value()
** 29-10-2012 del ICT_SLAVE
** 30-10-2012 renaming
** 01-11-2012 generate PPM with ISR
** 04-11-2012 flash() led, test mode optional
** 25-12-2012 ISR(TIMER1_COMPA_vect) added support for print ppm
** 30-12-2012 version 1.1.0: SOFTWARE_VERSION, CommitChanges_bool
** 05-01-2013 version 1.1.1: ComputeChannelPulse() dual rate
** 12-01-2013 version 1.1.2 (12548 bytes): replaced NCHANNELS by CHANNELS
** 13-01-2013 version 1.1.2a (12620 bytes): set back Serial 9600 Bauds because 115200 was causing issues when pasting multiple lines
** 23-02-2013 version 1.1.4 ComputeChannelPulse() integer math, deleted arg enable_calibration_bool from ComputeChannelPulse()
** 24-02-2013 input validation in command mode
** 02-03-2013 version 1.1.4a renamed TEST_SWITCH_PIN as MODEL_SWITCH_PIN, always defined, deleted TEST_MODE
** 03-03-2013 version 1.1.4a moved led management to new class ArduinotxLed
** 05-03-2013 version 1.1.4c fixed all compilation warnings, ArduinotxLed displays morse characters
** 08-03-2013 v1.1.4d Throttle channel defined for each model
** 09-03-2013 10:41:00 v1.1.4e disabled PPM during setup() 
** 30-04-2013  v1.1.4g command line serial input may be '\n' or '\r' terminated; ECHO UPLOAD for txupload utility
** 01-05-2013 v1.2.0 class ArduinoTx
** 02-05-2013 v1.2.1  ignore comments in commands
** 03-05-2013 v1.2.2 Mixers
** 04-05-2013 v1.2.2a
** 12-05-2013 v1.2.3 deleted 2 unused constants in arduinotx_transmitter.h
** 16-05-2013 v1.2.4 Command mode: removed ECHO OFF from DUMP output, allow 0 input for N1M,N2M in validate_value(), ArduinoTx::ReadControl()
** 06-06-2013 v1.2.5 moved arrays to PROGMEM, Exponential
** 29-06-2013 txupload: added optional arg to resume upload at line number 
** 04-07-2013 v1.3.0 Comments start by '#' instead of ';'
** 12-08-2013 v1.3.1 arduinotx_lib
** 13-08-2013 v1.3.2 LED_PIN, ArduinoTx::Init()
** 14-08-2013 v1.3.2  ArduinotxLed, ArduinotxBuzz, getProgmemStrpos(), getProgmemStrchr()
** 15-08-2013 v1.3.2 ArduinotxBuzz PlayCount_byt
** 17-08-2013 v1.3.2 ArduinotxBuzz, ArduinotxLed OK, Init() fixed, check_throttle() avarages throttle pot readings
** 18-08-2013 v1.3.2 buzzes 3 times current mode
** 18-08-2013 v1.4.0 ArduinoTx::check_battery(), GLOBAL_BAT
** 20-08-2013 v1.4.0 TXREFRESH_PERIOD = 50, ArduinoTx::Refresh() calls check_battery() every 5s
** 23-08-2013 v1.4.0  ArduinoTx::Init() fixed pinmode initialization
** 24-08-2013 v1.4.0  ComputeChannelPulse() fixed underflow in subtrim computation, this bug existed in v1.3 for negative values of CHAN_SUB< -10%
** 25-08-2013 v1.4.0  var BAT ok in cmd mode
** 26-08-2013 v1.4.0  changed Morse codes flashed on the Led
** 28-08-2013 v1.4.0 Battery check
** 31-08-2013 v1.4.0 Battery check ok
** 01-09-2013 v1.4.0 BAT default value  = 740	Flash=19298	Ram=683

** 08-09-2013 v1.5.0 branche /arduinorc/branches/moreswitches
** 14-05-2014 implemented MODEL_SWITCH_STEPPING
** 16-05-2014 v1.5.1 implemented MODEL_SWITCH_ROTATING; MODEL_SWITCH_BEHAVIOUR defaults to MODEL_SWITCH_STEPPING
** 26-05-2014 v1.5.2 full curve exponential may apply to the throttle channel
** 28-05-2014 v1.5.3 new bilinear endpoints algorithm; moved all user-customizable settings to arduinotx_config.h
** 29-05-2014 v1.5.4 new PRINT VOLT command displays battery voltage; EPL, EPH : End point percentage [51-100]
** 30-05-2014 v1.5.5 changed Endpoints semantics: now EPL,EPH: [0,100] defines end point position in % from the center ; 
	lowered command mode's serial speed to 2400 bps to prevent Arduino's serial buffer overflow when uploading with txupload; 
** 01-06-2014 v1.5.5 fixed cond compil of ReadBattery()
	avr-size: Flash=19808 Ram=686

Notice: avr-size reports memory usage for Arduino Nano ATmega328 with CHANNELS=6, BUZZER_ENABLED, BATCHECK_ENABLED, MODEL_SWITCH_BEHAVIOUR=MODEL_SWITCH_STEPPING, ENDPOINTS_ALGORITHM=ENDPOINTS_BILINEAR

Copyright (C) 2014 Richard Goutorbe.  All right reserved.
This program is free software: you can redistribute it and/or modify it under the terms of the GNU General Public License as published by the Free Software Foundation, version 3.
This program is distributed in the hope that it will be useful, but WITHOUT ANY WARRANTY; without even the implied warranty of  MERCHANTABILITY or FITNESS FOR A PARTICULAR PURPOSE.
See the GNU General Public License for more details. You should have received a copy of the GNU General Public License along with this program.  If not, see <http://www.gnu.org/licenses/>.
Contact information: http://www.reseau.org/arduinorc/index.php?n=Main.Contact
*/

/*
** Resources -----------------------------------------------
*/

#include <EEPROM.h>
#include "arduinotx_lib.h"
#include "arduinotx_eeprom.h"
#include "arduinotx_led.h"
#include "arduinotx_command.h"
#include "arduinotx_transmitter.h"
#ifdef BUZZER_ENABLED
#include "arduinotx_buzz.h"
#endif

/*
** Global declarations -----------------------------------------------
*/

// Tx manager
ArduinoTx ArduinoTx_obj;

// Command mode interpreter
ArduinotxCmd Command_obj;

// EEPROM manager
ArduinotxEeprom Eeprom_obj;

// Led manager
ArduinotxLed Led_obj(LED_PIN);

#ifdef BUZZER_ENABLED
// Buzzer manager
ArduinotxBuzz Buzzer_obj(BUZZER_PIN);
#endif

// These 2 global variables are used to request the PPM signal values from ISR(TIMER1_COMPA_vect)
volatile byte RequestPpmCopy_bool = false;
volatile unsigned int PpmCopy_int[CHANNELS]; // pulse widths (microseconds)


/*
** Arduino specific functions -----------------------------------------------------------------
*/
/*
const char MVNstring_0[] PROGMEM = "FRSKYX";
const char MVNstring_1[] PROGMEM = "FRSKYD";
const char MVNstring_2[] PROGMEM = "BAYANG";
const char MVNstring_3[] PROGMEM = "ERROR ";
PGM_P const ModelVarNames_str[] PROGMEM = {MVNstring_0,MVNstring_1,MVNstring_2,MVNstring_3};
*/

void setup() {

	//analogReference(INTERNAL);
	noInterrupts(); // No PPM signal until initialization complete
	ArduinoTx_obj.Init();
	interrupts();

}

/* serialEvent() occurs whenever a new data comes in the hardware serial RX. 
** This routine is run between each time loop() runs, so using delay inside loop()
** can delay response. Multiple bytes of data may be available.
*/
void serialEvent() {
	if (Serial.available())
		Command_obj.Input();
}

//~ volatile unsigned int DebugValue_int = 0; // debug
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

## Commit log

2017-05-01 Adjust sketch and schematic
    [MiniTx_Er9XR_PRO.kicad_pcb, MiniTx_Er9XR_PRO.sch]
2017-05-02 schematic adjustments
    [MiniTx_Er9XR_PRO.sch]
2017-05-02 Not sure how many changes
    [MiniTx_Er9XR_PRO-F.Cu.dxf, MiniTx_Er9XR_PRO.kicad_pcb, MiniTx_Er9XR_PRO.sch]
2017-05-03 Schematic values adjust
    [MiniTx_Er9XR_PRO.sch]
2017-05-04 openscad model change
    [miniTX9xrPro.scad, miniTX9xrPro.stl]
2017-05-04 openscad model and reduced one button
    [MiniTx_Er9XR_PRO.sch, miniTX9xrPro.scad]
2017-05-05 Adjust CH5 analog input, OpenSCAD, Schematic
    [MiniTx_Er9XR_PRO.sch, miniTX9xrPro.scad]
2017-05-05 led resistor to 39 ohm
    [MiniTx_Er9XR_PRO.sch]
2017-05-14 Another version (easier to print)
    [miniTX9xrProV2.scad]
2017-05-15 version 2 case adjsutment
    [miniTX9xrPro.stl, miniTX9xrProV2.scad, miniTX9xrProV2_middle.stl]
2017-05-16 small changes to the middle part. Also finished upper and lower parts
    [miniTX9xrProV2.scad, miniTX9xrProV2_middle.stl]
2017-05-16 first real print
    [miniTX9xrProV2.scad, miniTX9xrProV2_antCoverX2.stl, miniTX9xrProV2_antX2.stl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]
2017-05-16 stl/gcode change
    [miniTX9xrProV2.scad]
2017-05-24 Some images for easy solder
    [miniTX9xrProV2_spacers.scad, miniTX9xrProV2_spacers.stl]
2017-05-24 Fix firmware for proper compiling with latest Arduino
    [arduinotx.ino, arduinotx_buzz.cpp, arduinotx_command.cpp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]
2017-05-25 Changed MODE switch to button (2 seconds press switches the MODE)
2017-05-26 Moved Throttle cut to A6. Model change is cycled only with configured models
2017-05-27 use INTERNAL voltage reference for Arduino
2017-05-29 Various schematics added as a reference
2017-05-29 Adjust schematic to have correct pin mapping
    [MiniTx_Er9XR_PRO.sch]
2017-05-30 TX module selection fix
    [Multiprotocol.ino, arduinotx_transmitter.cpp]
2017-06-02 Reverted to VCC voltage reference
    [arduinotx.ino, arduinotx_command.cpp, arduinotx_config.h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]
2017-06-03 ThrottleCut should not take to account REV on output
2017-06-26 Images of 2.4 Dipole Antenna

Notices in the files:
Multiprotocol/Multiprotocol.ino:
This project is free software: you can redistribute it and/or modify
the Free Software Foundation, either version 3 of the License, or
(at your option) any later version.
